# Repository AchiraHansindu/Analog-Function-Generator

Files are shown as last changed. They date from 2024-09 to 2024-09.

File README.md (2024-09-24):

# Analog Function Generator

## Overview
This repository contains the design and implementation details of an Analog Function Generator capable of producing multiple waveforms. This device offers adjustable parameters such as frequency, amplitude, and DC shift, suitable for a wide range of applications in electronics testing and research.

## Key Features
- **Waveforms**: Generates sine, triangle, saw-tooth, square, and PWM waves.
- **Frequency Range**: Adjustable from 20 Hz to 20 kHz.
- **Amplitude Control**: 0 to 10 V peak-to-peak with fine resolution adjustments.
- **DC Shift and Duty Cycle**: Adjustable DC shift and variable duty cycle from 2% to 98% for PWM waves.
- **Energy Efficiency**: Optimized for low power consumption while maintaining high-quality output.

## Specifications
- **Frequency Accuracy**: ±0.1%.
- **Amplitude Resolution**: 0.1V.
- **Output Characteristics**: Capable of driving a 50-ohm load, with minimal harmonic distortion (less than 0.5% for sine waves).

## Hardware Design
### Circuit Components
- **Operational Amplifiers**: AD711JN, TL072CP, AD712JN for precise waveform generation.
- **Transistors**: TIP31C and TIP32C in a class-AB push-pull configuration for enhanced current driving capabilities.

### PCB and Enclosure
- **PCB**: Designed with Altium as a two-layer board, focusing on efficient current handling and signal integrity.
- **Enclosure**: Robust design using SolidWorks, ensuring durability for lab environments.

## Control Panel
- **Wave Selection**: Toggle between different waveforms.
- **Frequency and Amplitude Adjustments**: Dedicated knobs for setting the waveform frequency and amplitude.
- **Duty Cycle Control**: Separate controls for adjusting the duty cycle of PWM and saw-tooth waveforms.

## Testing and Performance
Extensive testing on breadboards followed by final PCB implementation confirms that the function generator meets all specified performance criteria, with precise control over waveform characteristics.

## Acknowledgements
Grateful acknowledgment to Mr. Pankajan for mentorship, and thanks to the project team for their dedicated efforts:
- [Alahakoon U.M.Y.B.](https://github.com/YasiruAlahakoon)
- [Dulnath W.H.R.]()
- [Hansindu K.A.A.](https://github.com/AchiraHansindu)
- [Shamika K.A.M.]()

## License

This project is licensed under the MIT License - see the [LICENSE](https://github.com/AchiraHansindu/Analog-Function-Generator/blob/main/LICENSE) file for details.

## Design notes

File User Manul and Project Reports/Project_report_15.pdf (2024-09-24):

## University of Moratuwa

## Faculty of Engineering

## Department of Electronic & Telecommunication Engineering

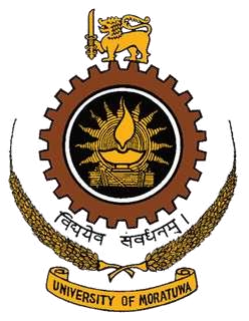
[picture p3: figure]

EN2091 - Laboratory Practice and Projects Group 15
Project Report - Analog Function Generator

Group Members

Index No. | Name
210027CJ 210152E 210204R 210600D | Alahakoon U.M.Y.B Dulnath W.H.R Hasindu K.A.A Shamika K.A.M.

Abstract

The design and development of an analogue function generator that can produce sine, sawtooth, square, and PWM waves with tunable amplitude, frequency, and DC shift is covered in depth in this report. It is feasible to adjust the frequencies from 20 Hz to 20 kHz and the amplitudes between 0 V and 10 V. The major components used in this project are resistors, capacitors, and op-amps.1

## Contents

1. Introduction | 4
2. Electronic Design
2.2.3.P.W.M Wave | 5
2.3.4.DC Shift | 7
3. Calculations and Component Selection 4
4. Simulations | 8
5. Testing | 9
6. PCB Designing and Soldering | 9
7. Results | 9
8. Enclosure Design | 10
9. Discussions | 10
10. Acknowledgement | 10
11. Bibliography | 10
12. Appendices | 11
12.4. | Team Members & Task Allocation | 15
12.5. | Bill of Quantities | 15

## 1 Introduction

We were required to create a fully functioning
function | generator | for | this | project,
which consists of every essential laboratory
function | generator | feature.creation | of
sine PWM wave, sawtooth, square, and triangle forms are the primary features of the generator of functions.Aside from that, this function generator can modify the wave patterns' frequency ranges from 20Hz 20kHz in frequency , 0 to 10V in amplitude . Adding a DC offset to the wave forms and add a changing the duty cycle of square
wave are the other functionalities of the function generator.

## 2 Electronic Design

### 2.1 Design Guidelines

For the analog function generator project we were given the following specifications to be fulfilled.

1. The function generator should be able to generate sine, triangular, saw-tooth, square and pulse width modulation (PWM) waves.
2. The frequencies of the waves should be able to vary from 20 Hz to 20 kHz.
3. The amplitudes of the waves should be able to vary up to 10 V peak-to-peak.
4. In PWM wave, the pulse width should be able to vary from 1% up to 99%.
5. The function generator should be able to supply the waves to a 50 Ω load.

### 2.2 Waveform Generation

As the given specifications, the function generator should be able to generate five functions namely, sine wave, square wave, triangular wave and PWM wave. We used separate methods to generate sine wave and other waves in colborate .

### 2.2.1 Square Wave Generation

The relaxation oscillator utilizes the charging and discharging of a capacitor through resistive elements to create a periodic square wave output. By integrating this oscillator configuration with operational amplifiers, the circuit can achieve precise control over frequency and amplitude. This innovative approach provides insights into the synergistic application of operational amplifiers and relaxation oscillators for reliable square wave generation, offering potential advantages in electronic signal processing and modulation applications.

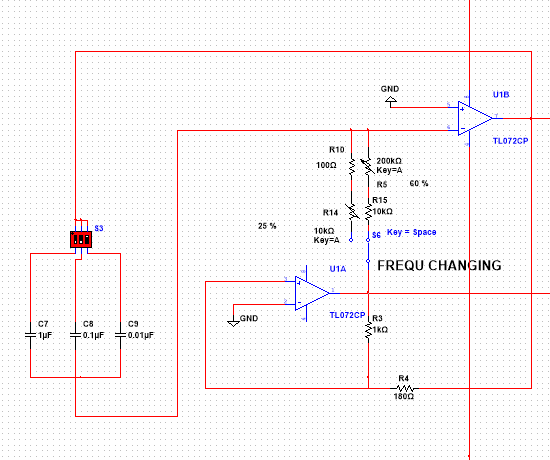
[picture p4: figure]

Figure 1: Square wave generator circuit.

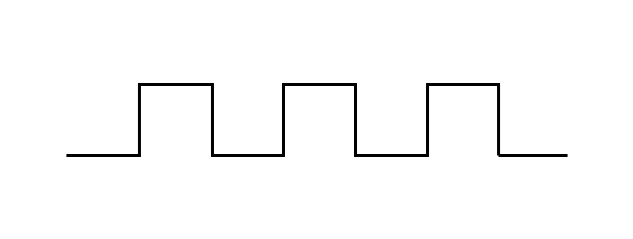
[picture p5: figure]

Figure 2: Square wave

Here we are using Op-Amp -AD711JN with Slew rate – 16V/us and Unity gain bandwidth – 3MHz

The triangular waveform is generated using the simple charging and discharging property of a capacitor.The frequency can be varied by changing the value of the capacitor and the variable resistors of the Schmitt

### 2.2.2 Triangular Wave Generation

The design uses a cascade combination of an integrator and a Schmitt trigger circuit to produce both square and triangular waveforms in the goal of creating a flexible analogue function generator. Hysteresis is introduced by the Schmitt trigger, guaranteeing a pure and noise-free square wave output. After being fed

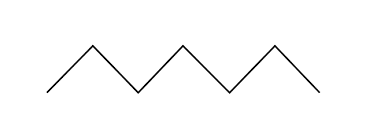
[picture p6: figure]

into an integrator, this square wave becomes a continuous triangular waveform. A distinct triangle waveform is produced as a result of the integration process, which smoothes the transitions between the high and low states.

### 2.2.3 PWM Wave Generation

By comparing a triangular waveform with a DC level, the experiment investigates the c reation of Pulse Width Modulation (PWM) signals, With this technique, the amplitude of a triangle waveform is used to modulate the width of pulses in a square wave.
It is possible to efficiently vary the PWM si

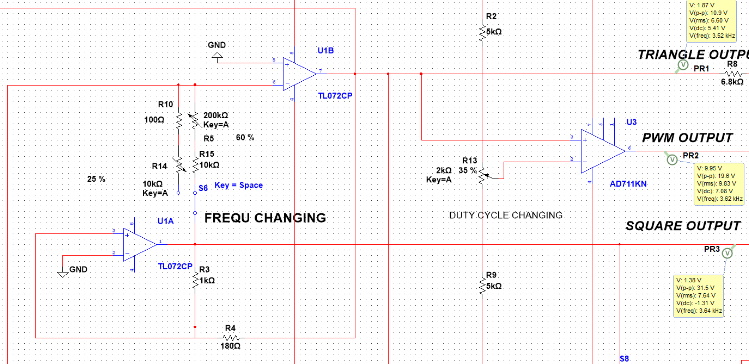
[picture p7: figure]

gnal's duty cycle by varying the resistance value in the circuit.DC value is obtained as a series connection through up and low voltage values.

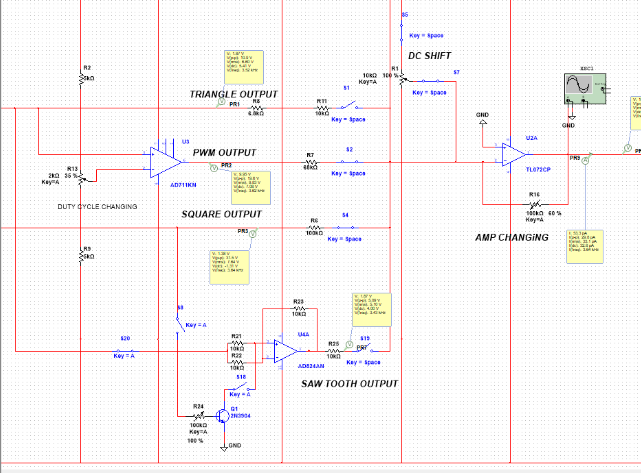
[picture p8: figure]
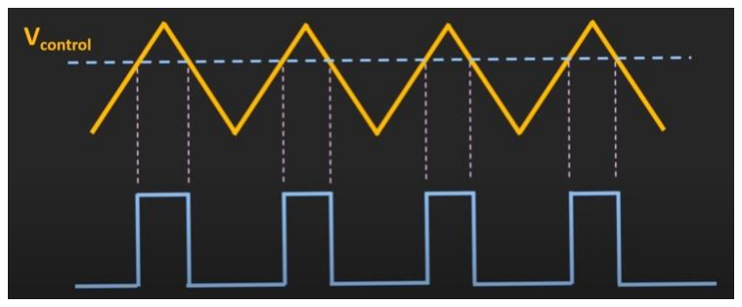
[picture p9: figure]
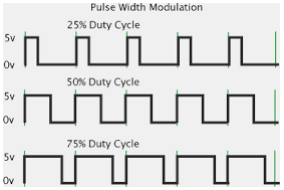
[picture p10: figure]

### 2.2.4 Sine Wave Generation

The bridge's frequency-sensitive arms are made up of the resistance R and capacitor C. The feedback path is composed of the resistances Rf and R1. The resistances Rf and R1 can be used to change the noninverting op-amp's gain. The op-amp's gain is

In order to meet the requirements of Barkhausen , where Aβ must be greater than 1, the noninverting op-amp amplifier's gain must be at least 3. So with that we get the equation for the frequency as

### 2.3 Output Circuit

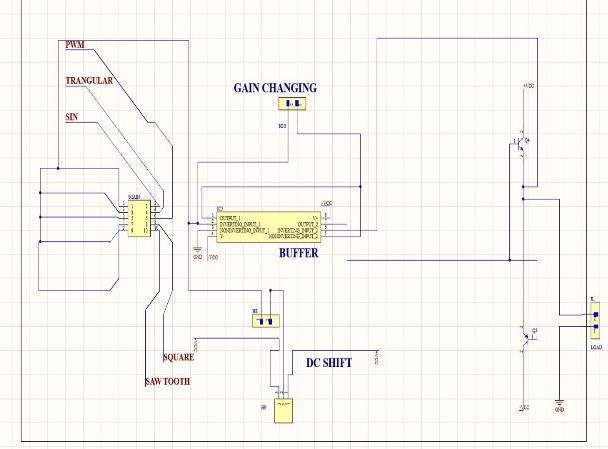
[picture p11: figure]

### 2.3.1 Waveform selection

Between the sine,square,triangular circuits and the output circuit, a switch is used to select which waveform generating circuit should be connected to the output circuit.

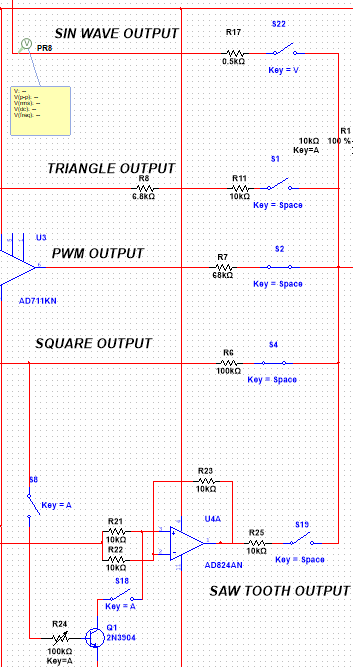
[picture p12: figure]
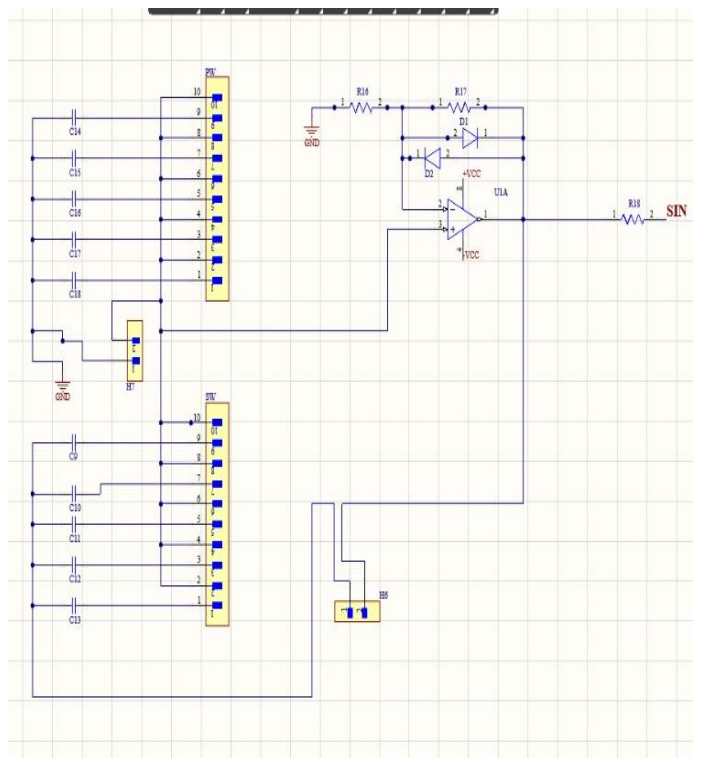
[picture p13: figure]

### 2.3.2 Amplitude control

An inverting amplifier is being used to vary the amplitude of he waveform.The main amplitude change of the wave forms is done using this amplifier.

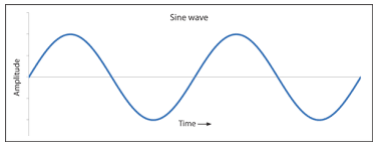
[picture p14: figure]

### 2.3.4 Push pull amplifier

At the output stage of the function generator a push-pull amplifier is used to am plify the current. This helps it to drive a small load without any distortion in the wave. In the design a class-AB push-pull amplifier is used.The two pnp and npn transistors are complementary to each other. The npn transistor drives the output during the positive half cycle of the input while the pnp transistor drives the output during the negative half cycle. These transistors should also be capable of handling the desired amount of power and current. The two diodes keep both the transistors biased thus eliminating the crossover distortion.

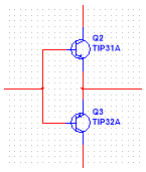
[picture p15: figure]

### 2.3.5 DC Shift

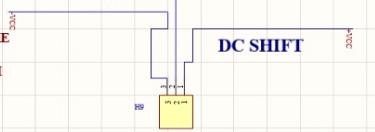
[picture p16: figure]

## 3 Calculations and Component Selection

Selecting components is very important for for the correct functionality of the function generator. We have done this using necessary calculations and by referring to the data sheets of the components

### 3.1 Opamp selection

In this circuit, all the waveform generations and amplifications are done using several
opamps.We | have | selected
AD711JN,Tl072CP5,AD712JN opamp to meet the given specifications.

### 3.1.2 AD711JN

We have selected the AD711JN operational
amplifier | to | meet | the | specified
requirements. This precision op-amp is chosen for its low noise characteristics, a crucial factor in achieving accurate signal processing. The AD711JN features a commendable slew rate 16V/us, ensuring
swift | voltage | transitions, | which | is
particularly | vital | for | square | wave
generation. Additionally, this op-amp possesses a gain-bandwidth product (GBP)
of 3MHz. | Considering | the | function
generator's required bandwidth of 20 kHz, the maximum gain achievable without introducing distortion can be calculated using the formula:
Maximum | Gain | = | GBP/Bandwidth.
Substituting the values, we obtain 150 which is more than sufficient to generate the desired 10V peak-to-peak output waveforms
Here for Square and triangular wave generation we are using this opamp.

### 3.1.2 TL072CP

TL072CP operational amplifier from Texas Instruments has been integrated into the circuit design. Renowned for its versatility and widespread use, the TL072CP operates with a wide bandwidth, typically in the MHz range. This op-amp features low input bias and offset currents, making it suitable for audio applications and general-purpose amplification. For sine and sawtooth wave generation we are using this opamp.

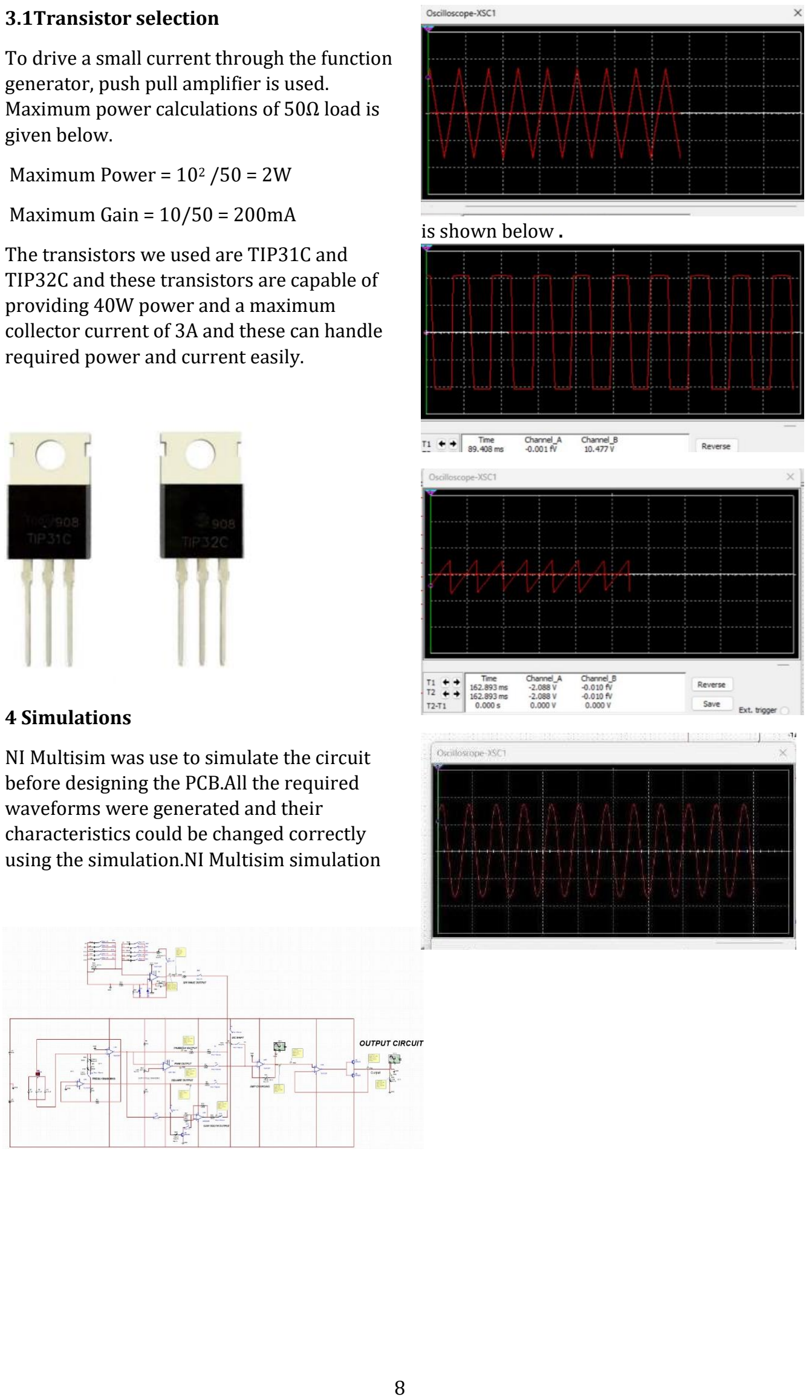
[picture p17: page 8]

3.1Transistor selection

To drive a small current through the function generator, push pull amplifier is used. Maximum power calculations of 50Ω load is given below.

Maximum Power = 10² /50 = 2W

Maximum Gain = 10/50 = 200mA

The transistors we used are TIP31C and TIP32C and these transistors are capable of providing 40W power and a maximum collector current of 3A and these can handle required power and current easily.

### 4 Simulations

NI Multisim was use to simulate the circuit before designing the PCB.All the required waveforms were generated and their characteristics could be changed correctly using the simulation.NI Multisim simulation

is shown below .

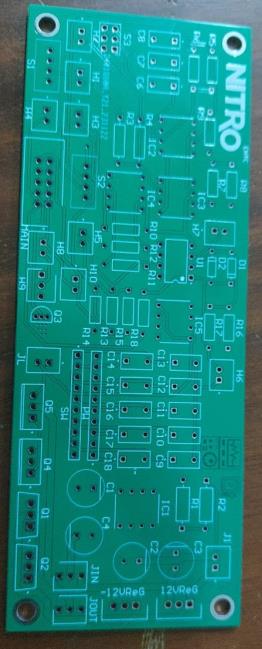
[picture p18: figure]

### 5 Testing

We built and tested the circuit on a breadboard following the circuit simulations. After a few tries, we were able to obtain distinct
waveforms with tunable frequencies and amplitudes within the recommended range despite some initial difficulties. The other square and triangle wave shapes were being impacted by the sin wave produced by the Wien bridge oscillator. We could reduce this problem with decoupling capacitors for each integrated circuit to some extent.We came to the conclusion that a breadboard, wire resistance, and sloppy connections were the main causes of the wave forms' instabilities.

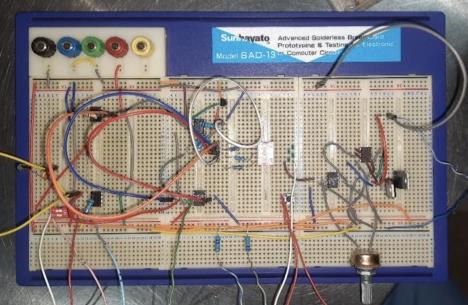
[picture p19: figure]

### 6 PCB Designing and Soldering

With Altium, we created a two-layer PCB. The ground was connected to both of the planes. We kept the power line width at 3mm and the normal line trace width at 0.2mm as our circuit does take more current than A. Our PCB design was printed by JLCPCB China.

After that, we checked the connections after soldering the PCB using parts that we sourced locally.

After making sure there were no disconnections, we examined the PCB in the lab to see if the appropriate waveforms were there.

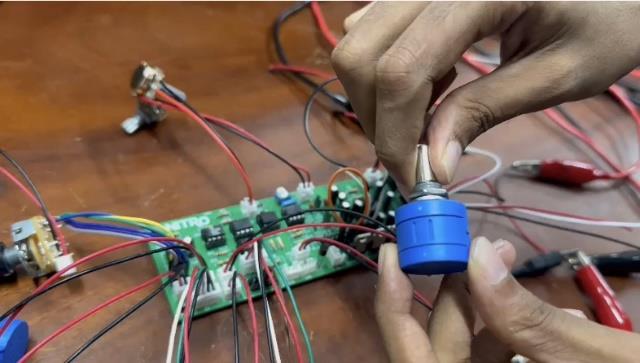
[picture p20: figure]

### 7 Results

The results we achieved are as follows. Square and PWM Wave

- we were able to achieve a frequency of more than 20kHz.

10µF : 10Hz - 270Hz

1µF : 200Hz - 2kHz

100nF : 2kHz - 66kHz

Triangular and Saw Tooth Wave

- we were able to achieve a frequency of more than 20kHz.

10µF : 17Hz - 400Hz

1µF : 35Hz - 700Hz

100nF : 350Hz - 6kHz

100pF : 3.5kHz - 27kHz

Sine Wave • we were able to achieve a frequency of more than 20kHz.

10µF : 17Hz - 400Hz

1µF : 35Hz - 700Hz

100nF : 350Hz - 6kHz

1nF : 3.5kHz - 27kHz

### 8 Enclosure Design

The enclosure was designed using Solidworks 2020.Photos are shown in the

appendix

### 9 Discussions

At high frequencies, there are distinct distortions at some waveforms. We can implement strategies to further reduce those distortions.

- Using high-quality resistors, capacitors, and opamps will help. The change in capacitor values results in distorted sin waves. Morever we had an issue with locally sourced dual gang potenneiometers.
- Wires can have considerable resistance which results in distortions. So can minimize the use of wires and ensure the stability of the connection.

### 10 Acknowledgement

Throughout this project, we were guided and aided by so many personalities. We would like to extend our sincere gratitude to our project mentors, Mr.Pankajan, whose unwavering commitment and keen enthusiasm in our undertaking contributed to the success of our project. Additionally, we would like to thank all those who contributed in even the slightest way for us to achieve this goal.

### 11 Bibliography

1. https://resources.pcb.cadence.com/blog/2020-designing-a-wien-bridge-oscillator-for-sine-wave-generation (https://resources.pcb.cadence.com/blog/2020-designing-a-wien-bridge-oscillator-for-sine-wave-generation)
2. https://www.ques10.com/p/22759/explain-triangular-wave-generator-using-opamp-1/#:~:text=A%20Triangular%20W ave%20Generator%20Using,capaci tor%20with%20a%20constant%2 0current. (https://www.ques10.com/p/22759/explain-triangular-wave-generator-using-opamp-1/)
3. https://www.ti.com/lit/an/snoa998/snoa998.pdf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 enerates%20a,R2%2C%20R3%2C %20and%20R4. (https://www.ti.com/lit/an/snoa998/snoa998.pdf?ts=1701855961777)
4. https://www.analog.com/en/analo g-dialogue/studentzone/studentzone -september-2021.html (https://www.analog.com/en/analog-dialogue/studentzone/studentzone-september-2021.html)
5. Sine Wave Generator using IC 741 OP AMP Operational Amplifier (electroniclinic.com) (https://www.electroniclinic.com/sine-wave-generator-using-ic-741-op-amp-operational-amplifier/)
6. Wien Bridge Sine Wave Oscillator / Generator » Electronics Notes (electronics-notes.com) (https://www.electronics-notes.com/articles/analogue_circuits/operational-amplifier-op-amp/wien-bridge-sine-wave-oscillator-generator.php)
7. Lower Power Op Amp: Utility Sine
Wave | Analog Devices (https://www.analog.com/en/technical-articles/lower-power-op-amp-utility-sine-wave.html)
8. Waveform Generator using Op Amp 741 - IC Applications and HDL Simulation Lab |
vikramlearning.com (https://vikramlearning.com/jntuh/notes/ic-applications-and-hdl-simulation-lab/waveform-generator-using-op-amp-741/298)
9. Increase Amplifier Output Drive Using a Push-Pull Amplifier Stage | Analog Devices (https://www.analog.com/en/technical-articles/increase-amplifier-output-drive-using-a-push-pull-amplifier-stage.html)
10. Analog Function Generator : 13 Steps (with Pictures) -
Instructables (https://www.instructables.com/Function-Generator/)

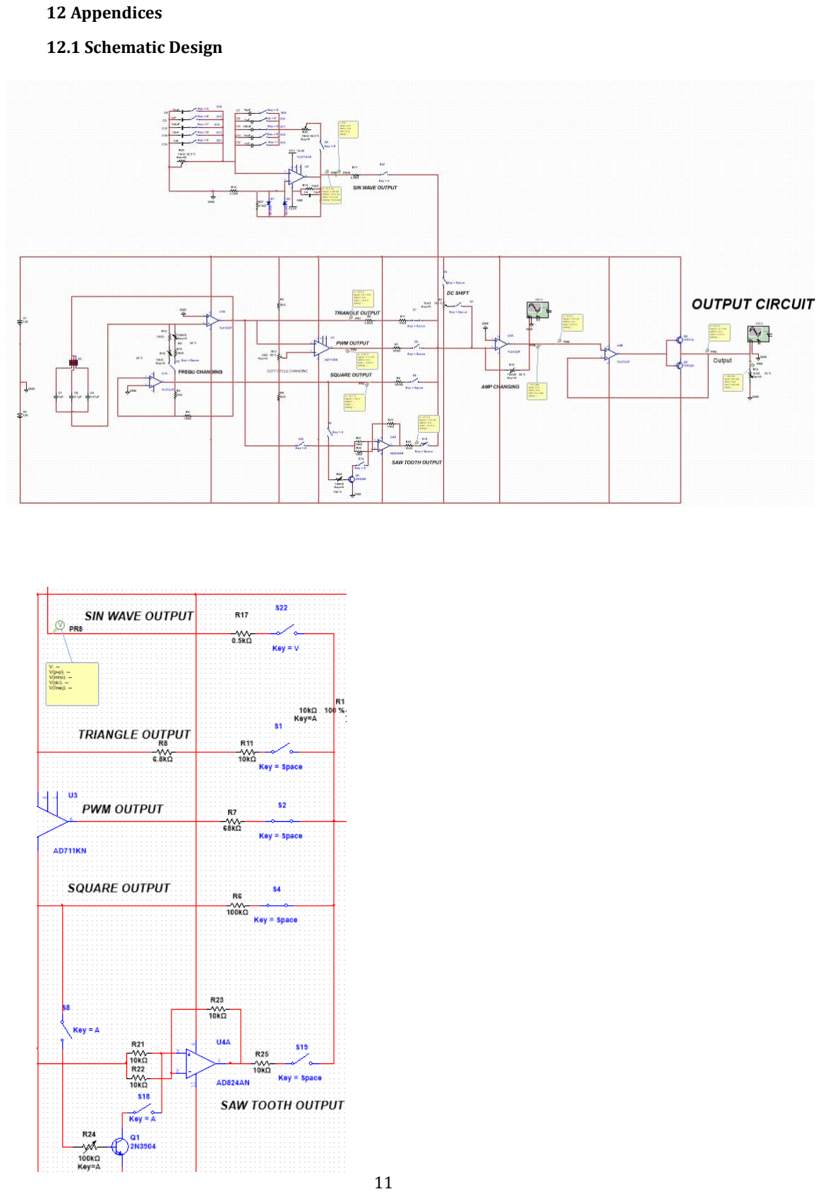
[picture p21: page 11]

### 12 Appendices

### 12.1 Schematic Design

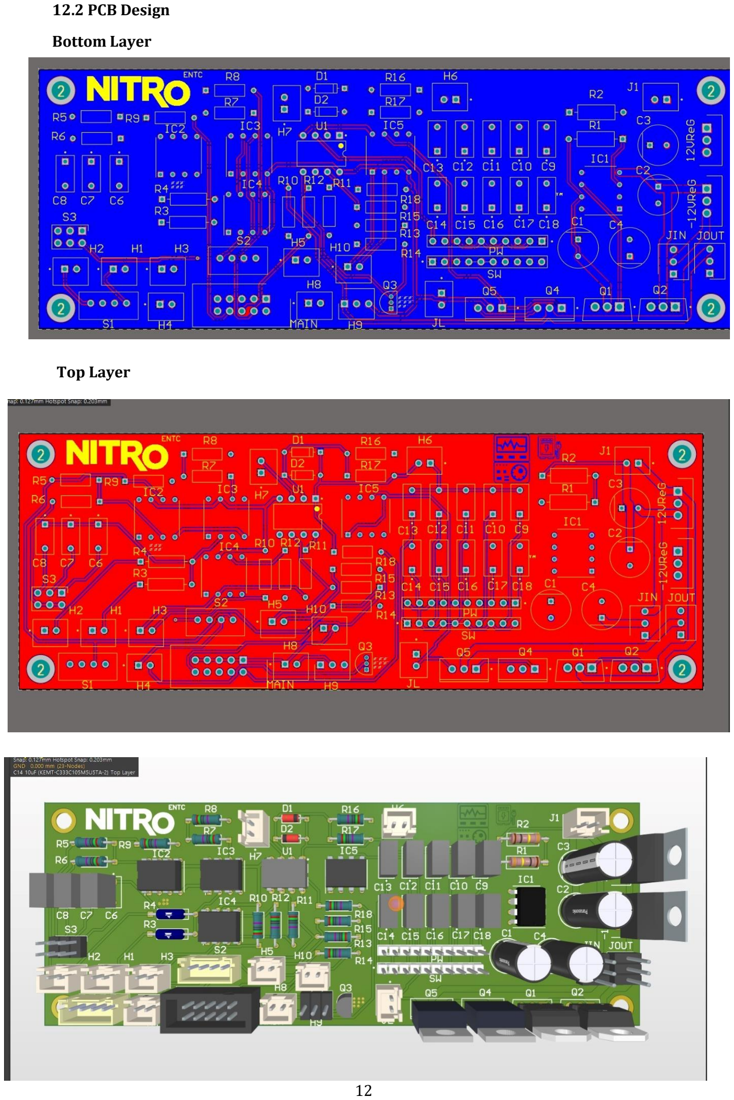
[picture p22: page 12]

### 12.2 PCB Design

Bottom Layer

Top Layer

Top Layer

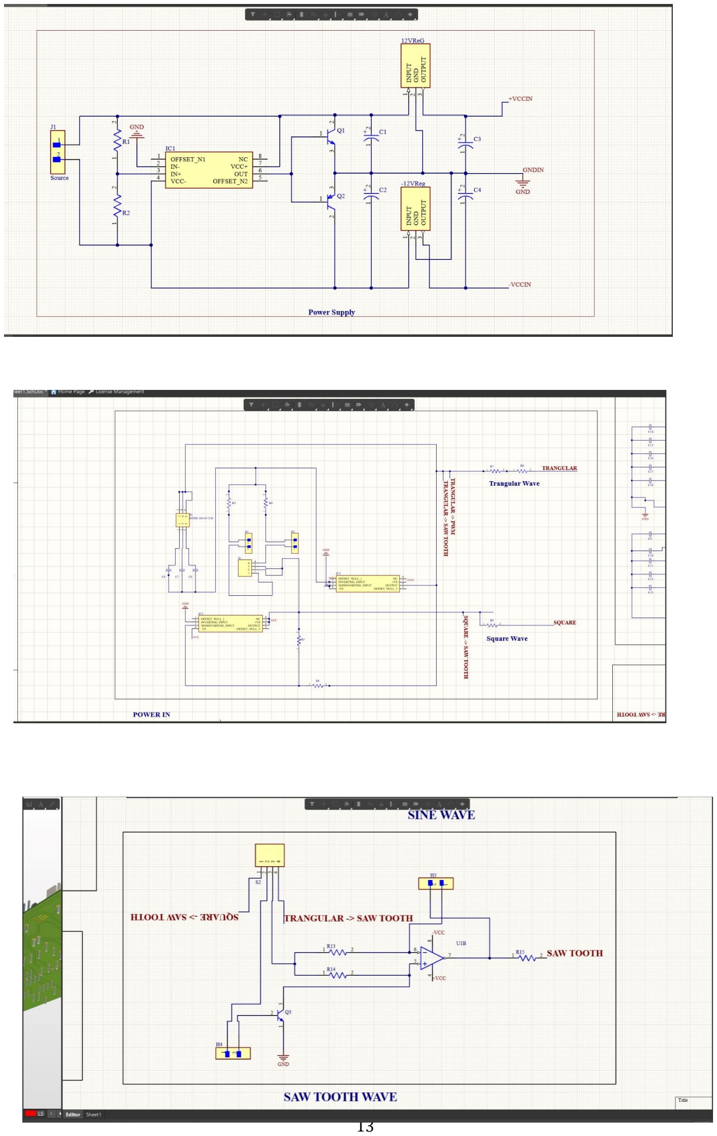
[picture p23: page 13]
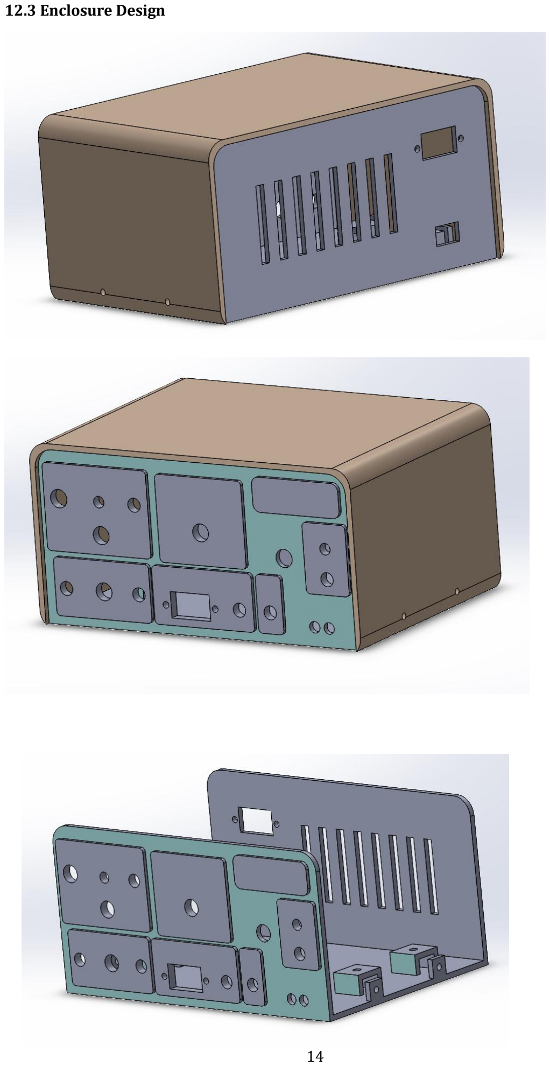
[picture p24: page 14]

### 12.3 Enclosure Design

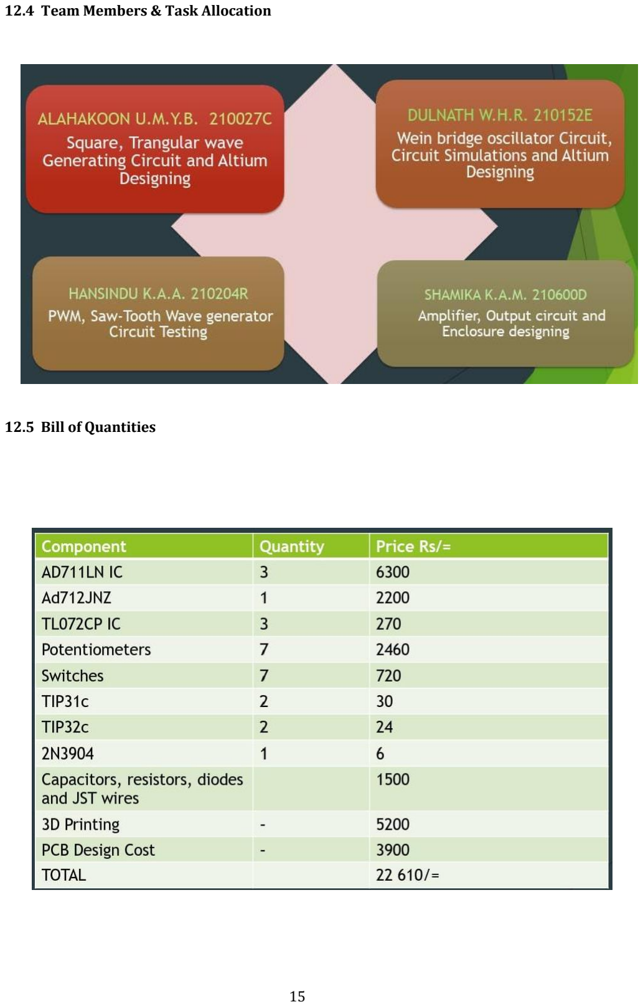
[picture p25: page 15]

### 12.4 Team Members & Task Allocation

### 12.5 Bill of Quantities

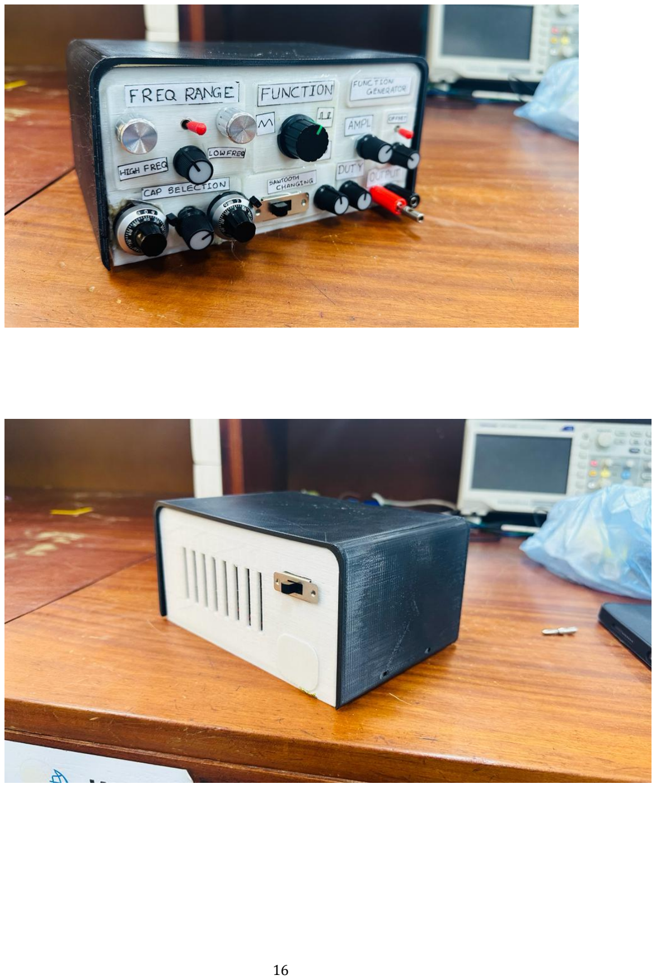
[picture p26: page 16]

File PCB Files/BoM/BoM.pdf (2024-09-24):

Comment | Description | Designator | Footprint | LibRef | Quantity
LM7812CT | Integrated Circuit | -12VReG, 12VReG | TO254P470X1028X195 5-3P | LM7812CT | | 2
EEUFR1E391L | Aluminum Electrolytic Capacitors (Radial Lead Type) 390uF ±20% 25V | C1, C2, C3, C4 | FP-RAD-TH-D_8_0_5-L_15_1-MFG | CMP-05427-000460-1 | | 4
1uF | Multilayer Ceramic Capacitor / Axial and Radial Leaded, 1 uF, +/-20%, 10 to 85 degC, 2-Pin THD, RoHS, Bulk | C6, C10, C15 | KEMT-C333C105M5U5TA-2 | CMP-2000-05174-1 | | 3
0.1uF | Multilayer Ceramic Capacitor / Axial and Radial Leaded, 1 uF, +/-20%, 10 to 85 degC, 2-Pin THD, RoHS, Bulk | C7 | KEMT-C333C105M5U5TA-2 | CMP-2000-05174-1 | | 1
0.01uF | Multilayer Ceramic Capacitor / Axial and Radial Leaded, 1 uF, +/-20%, 10 to 85 degC, 2-Pin THD, RoHS, Bulk | C8 | KEMT-C333C105M5U5TA-2 | CMP-2000-05174-1 | | 1
10uF | Multilayer Ceramic Capacitor / Axial and Radial Leaded, 1 uF, +/-20%, 10 to 85 degC, 2-Pin THD, RoHS, Bulk | C9, C14 | KEMT-C333C105M5U5TA-2 | CMP-2000-05174-1 | | 2
100nF | Multilayer Ceramic Capacitor / Axial and Radial Leaded, 1 uF, +/-20%, 10 to 85 degC, 2-Pin THD, RoHS, Bulk | C11, C16 | KEMT-C333C105M5U5TA-2 | CMP-2000-05174-1 | | 2
10nF | Multilayer Ceramic Capacitor / Axial and Radial Leaded, 1 uF, +/-20%, 10 to 85 degC, 2-Pin THD, RoHS, Bulk | C12, C17 | KEMT-C333C105M5U5TA-2 | CMP-2000-05174-1 | | 2
1nF | Multilayer Ceramic Capacitor / Axial and Radial Leaded, 1 uF, +/-20%, 10 to 85 degC, 2-Pin THD, RoHS, Bulk | C13, C18 | KEMT-C333C105M5U5TA-2 | CMP-2000-05174-1 | | 2
1N4148 | DIODE GEN PURP 100V 200MA DO35 | D1, D2 | FP-017AG-MFG | CMP-07163-000046-1 | | 2
LOAD | CONN HEADER VERT 2POS 2.5MM | H1, H2, H3, H4, H5, H6, H7, H8, H10, JL | FP-B2B-XH-A_LF_SN-MFG | CMP-2000-05888-3 | 10
0022232031 | Connector | H9, JIN, JOUT | HDRV3W87P0X254_1X 3_747X635X1105P | 0022232031 | | 3
TL071CP | Integrated Circuit | IC1 | DIP794W53P254L959H 508Q8N | TL071CP | | 1
AD711JN | Integrated Circuit | IC2, IC3, IC4 | DIP794W56P254L928H 457Q8N | AD711JN | | 3
AD712JNZ | Integrated Circuit | IC5 | DIP794W56P254L959H 533Q8N | AD712JNZ | | 1
Source | CONN HEADER VERT 2POS 2.5MM | J1 | FP-B2B-XH-A_LF_SN-MFG | CMP-2000-05888-3 | | 1
61201021621 | Connector | MAIN | _2036X885X925P SHDR10W64P254_2X5 | 61201021621 | | 1
in 1 | CONN HEADER VERT 10POS 2.54MM | PW | FP-4-644456-0-MFG | CMP-03369-000038-1 | | 1
TIP31C | TRANS NPN 100V 3A TO-220 | Q1 | FP-TO-220-P0A0015988-MFG | CMP-12195-000001-1 | | 1
TIP32C | TRANS PNP 100V 3A TO-220 | Q2 | FP-TO-220-P0A0015988-MFG | CMP-12195-000005-1 | | 1
SAWTOOTH | NPN General-Purpose Amplifier, 40 V VCEO, 0.2 A, -55 to 150 degC, 2-Pin TO-92, RoHS, Bulk | Q3 | FAIR-TO-92 | CMP-2000-04944-1 | | 1
TIP31A | Complementary Silicon Plastic Power Transistor, 3-Pin TO-220, Tube | Q4 | ONSC-TO-220-3-221A-09 | CMP-1048-01124-1 | | 1
TIP32A | Complementary Silicon Plastic Power Transistor, 3-Pin TO-220, Tube | Q5 | ONSC-TO-220-3-221A-09 | CMP-1048-01079-1 | | 1
100K | RES 100K OHM 5% 1W AXIAL | R1, R2 | FP-RR01-MFG | CMP-03212-000008-1 | | 2
150ohm | RLR07C7501GSB14 Res Metal Film 7.5K Ohm 2% 1/4W ±100ppm/°C 0.001% Conformal AXL Thru-Hole Bulk | R3 | FP-RLR07-MFG | CMP-00030-41139779-1 | | 1
10K | RLR07C7501GSB14 Res Metal Film 7.5K Ohm 2% 1/4W ±100ppm/°C 0.001% Conformal AXL Thru-Hole Bulk | R4 | FP-RLR07-MFG | CMP-00030-41139779-1 | | 1
1K | RES 10K OHM 0.6W 1% AXIAL | R5 | FP-MBB0207-MFG | CMP-02408-000035-1 | | 1
150OHM | RES 10K OHM 0.6W 1% AXIAL | R6 | FP-MBB0207-MFG | CMP-02408-000035-1 | | 1
6.8K | RES 10K OHM 0.6W 1% AXIAL | R7 | FP-MBB0207-MFG | CMP-02408-000035-1 | | 1
10K | RES 10K OHM 0.6W 1% AXIAL | R8, R9, R10, R11, R13, R14, R15, R17 | FP-MBB0207-MFG | CMP-02408-000035-1 | | 8
68Kohm | RES 10K OHM 0.6W 1% AXIAL | R12 | FP-MBB0207-MFG | CMP-02408-000035-1 | | 1
5K | RES 10K OHM 0.6W 1% AXIAL | R16 | FP-MBB0207-MFG | CMP-02408-000035-1 | | 1
0.5K | RES 10K OHM 0.6W 1% AXIAL | R18 | FP-MBB0207-MFG | CMP-02408-000035-1 | | 1
B4B-XH-A_LF__SN_ | Connector | S1, S2 | B4BXHALFSN | B4B-XH-A_LF__SN_ | | 2
HTSW-103-07-T-D | Connector | S3 | HDRV6W64P254_2X3_ 762X502X838P | HTSW-103-07-T-D | | 1
in2 | CONN HEADER VERT 10POS 2.54MM | SW | FP-4-644456-0-MFG | CMP-03369-000038-1 | | 1
TL072CP | Dual Low-Noise JFET-Input General-Purpose Operational Amplifier, 7 to 36 V, 0 to 70 degC, 8-pin DIP (P8), Pb-Free (RoHS) | U1 | P0008A | CMP-0017-00950-2 | | 1

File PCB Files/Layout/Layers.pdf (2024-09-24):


Top Layer

Bottom Layer

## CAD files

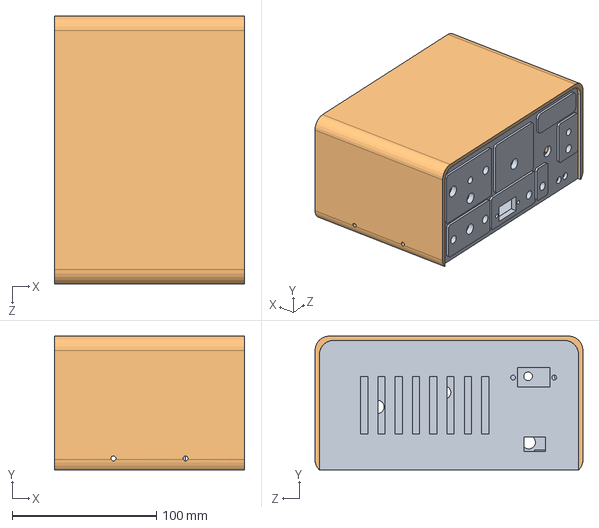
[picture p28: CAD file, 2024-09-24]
3D Design Solidworks/Assembly files/Fuc_Gen_Final.SLDASM
132.0 x 93.0 x 186.0 mm
Assem2
Top_Part

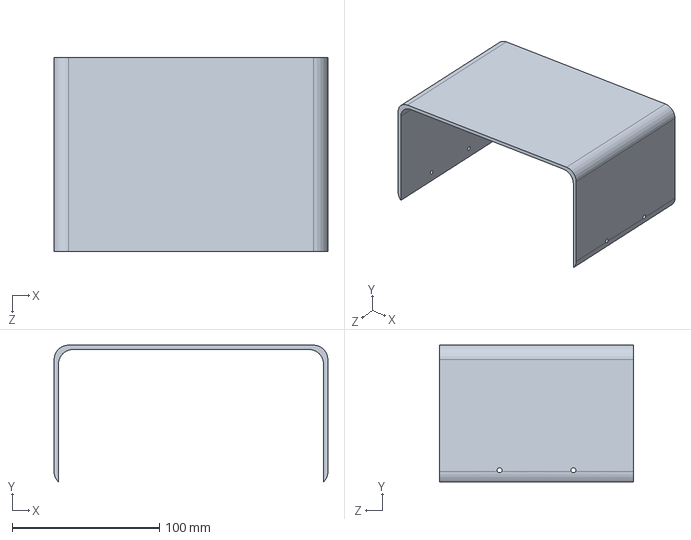
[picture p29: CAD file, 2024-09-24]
3D Design Solidworks/Solid Parts/Top_Part.SLDPRT
186.0 x 93.0 x 132.0 mm

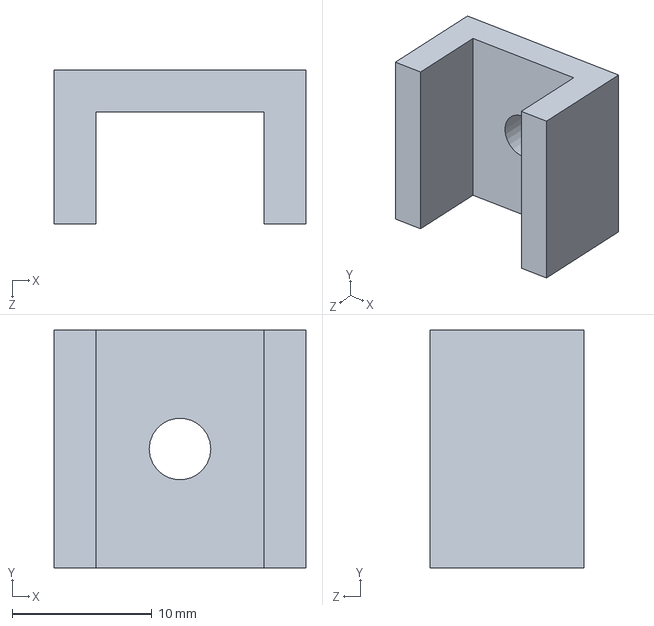
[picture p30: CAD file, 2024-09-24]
3D Design Solidworks/Solid Parts/PCB_Holder.SLDPRT
18.0 x 17.0 x 11.0 mm

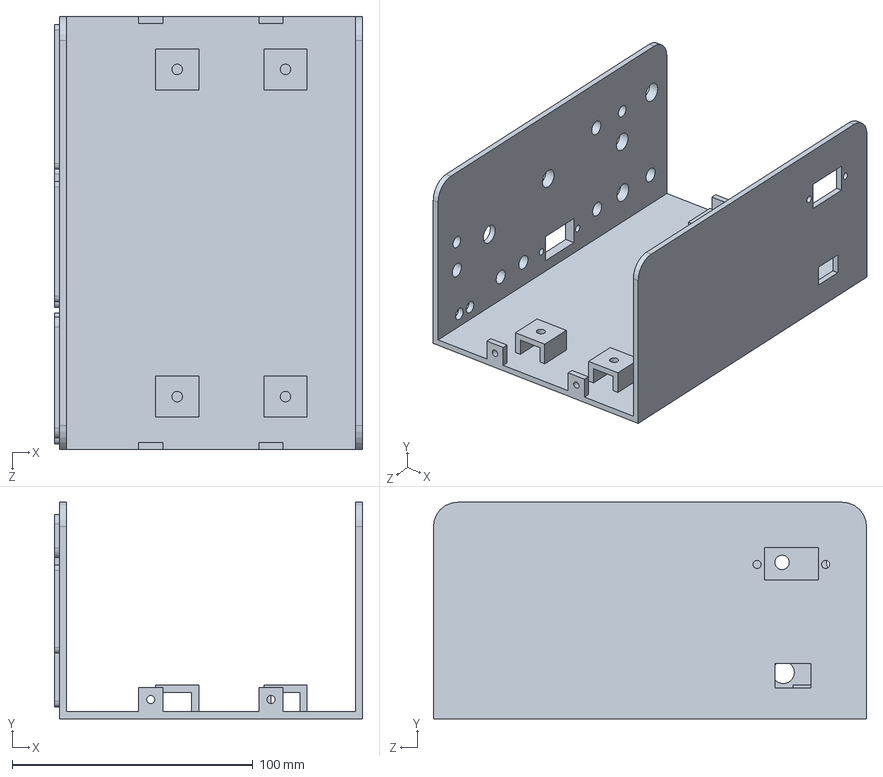
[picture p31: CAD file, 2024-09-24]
3D Design Solidworks/Solid Parts/Bottom_final.SLDPRT
128.0 x 90.0 x 180.0 mm

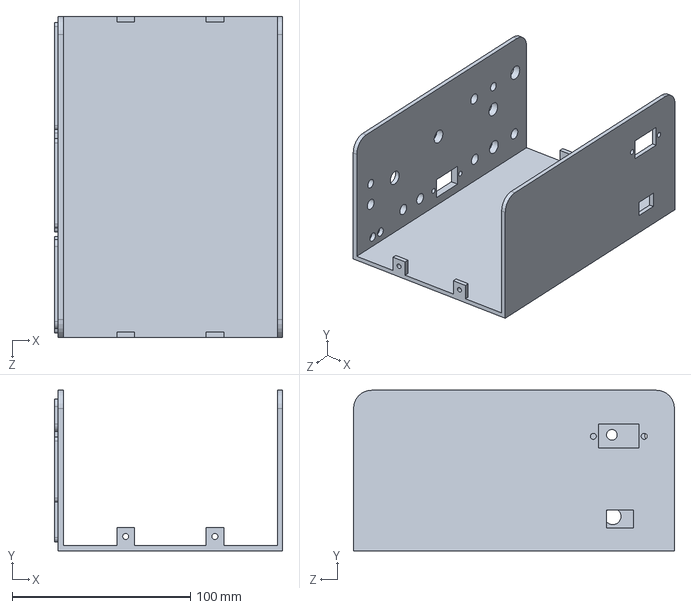
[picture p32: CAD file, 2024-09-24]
3D Design Solidworks/Solid Parts/Bottom part.SLDPRT
128.0 x 90.0 x 180.0 mm

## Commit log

2024-09-24 Added the 3D design files.
    [Bottom part.SLDPRT, Bottom_final.SLDPRT, Fuc_Gen_Final.SLDASM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]
2024-09-24 Added PCB Files.
    [Function Gene.PrjPcb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]
